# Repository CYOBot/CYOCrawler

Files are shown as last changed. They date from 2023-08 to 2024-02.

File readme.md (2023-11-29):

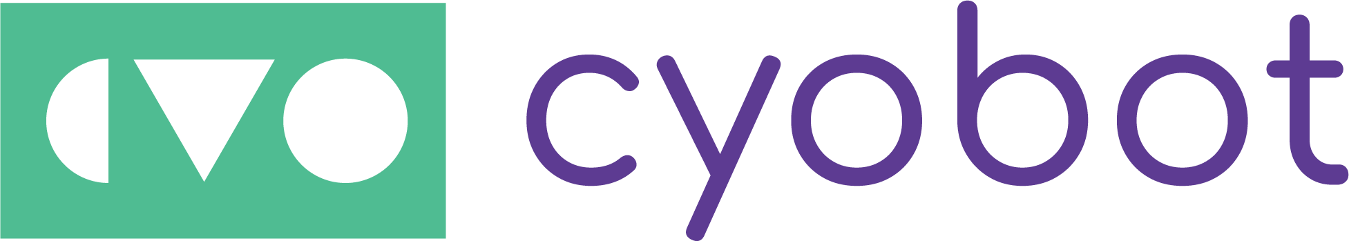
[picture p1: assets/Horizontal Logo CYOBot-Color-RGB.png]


# Introduction
This is the official repository of CYOBOT LLC **CYOCrawler, an open-source quadrupedal robotic platform**. 

CYOCrawler is the ultimate toolkit for beginner to advanced robotic adventures. The robot comes equipped with enough peripherals for most robotic applications, and extension block to connect further devices if needed. CYOCrawler comes with its own coding interface embedded, allowing seamless onboarding process for beginner, with more than enough project activities to learn and play. It is also open-source, welcoming advanced players to creatively level it up.

CYOCrawler is equipped with a wide range of capabilities to accompany you on your robotic journey:
- ESP32 Wi-Fi & Bluetooth MCU
- PCA9685 providing 12-channel servo controller
- LSM6D IMU
- Onboard speaker with MAX98357
- Onboard microphone with MAX9814
- 33-NeoPixel-LED matrix and 12-NeoPixel-LED ring
- Micro SD card reader
- USC C battery charger and smart charging/discharging system
- Extension block with power, I2C, SPI, UART, GPIO

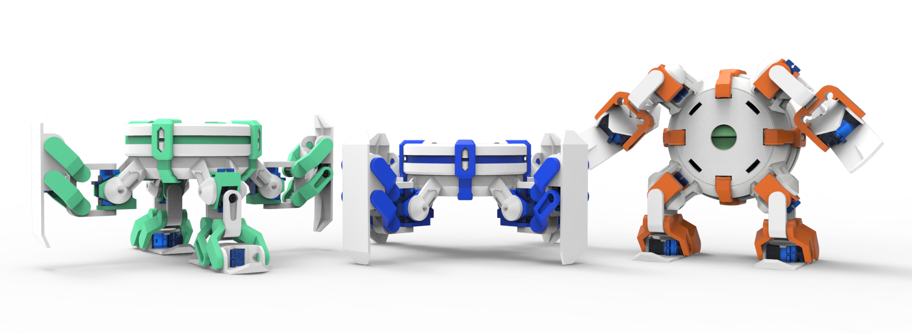
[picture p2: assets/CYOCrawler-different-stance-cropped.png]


<!-- More examples, tutorials and projects using CYOCrawler/CYOBrain can be found through [CYOBot's project library](https://cyobot.projectcocoon.org/) -->

More examples, tutorials and projects using CYOCrawler/CYOBrain can be found through [CYOBot's project library](https://cyobot.notion.site/a845040ff7484627a544b4d025d32f9d?v=201e9cd408014c6cad27ed2f8226b786&pvs=4)

Every week we publish a new challenge to our community at [r/CYOBot](https://www.reddit.com/r/CYOBot/). Join our Reddit community to participate in challenges and earn yourself a contribution on this repo. Refer to [Challenge](/challenges/readme.md) for more information.

# Technical Specification
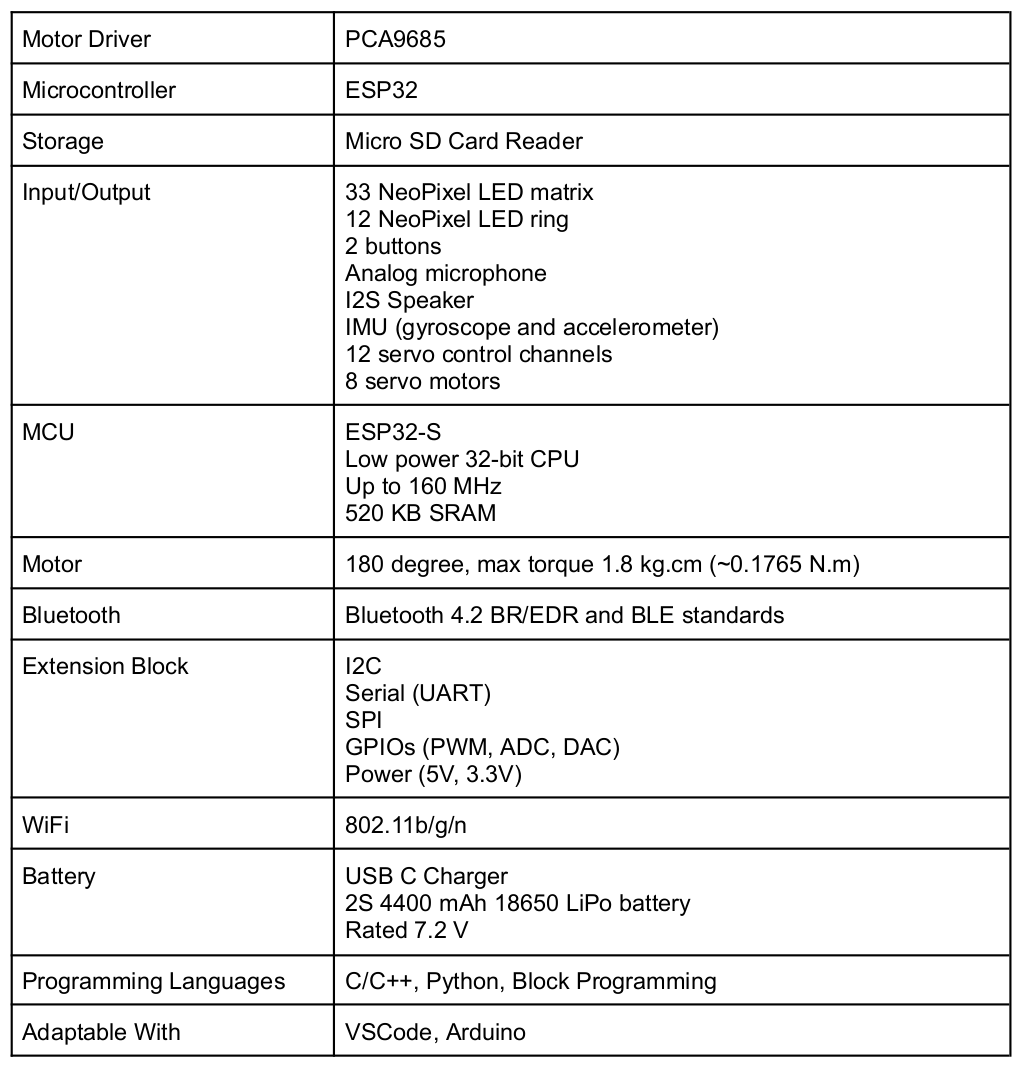
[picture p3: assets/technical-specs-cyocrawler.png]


# License
This product is open-source certified by OSHWA ([US002433](https://certification.oshwa.org/us002433.html)).

 

# Community
Follow us on social media and join the community!

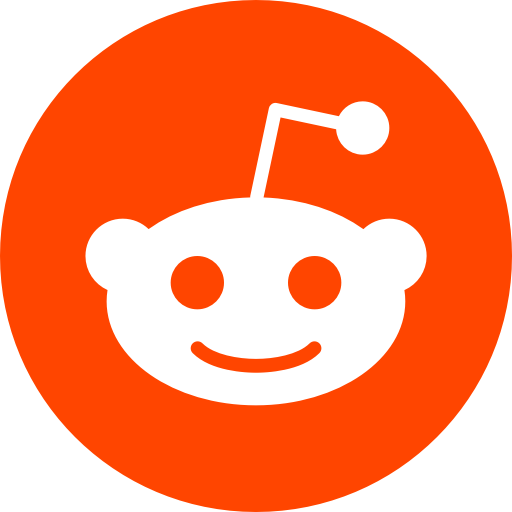
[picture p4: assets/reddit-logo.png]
[](https://www.reddit.com/r/CYOBot/)&nbsp;&nbsp;
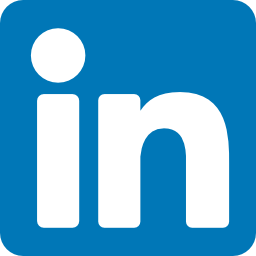
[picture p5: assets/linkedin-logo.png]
[](https://www.linkedin.com/company/cyobot)&nbsp;&nbsp;
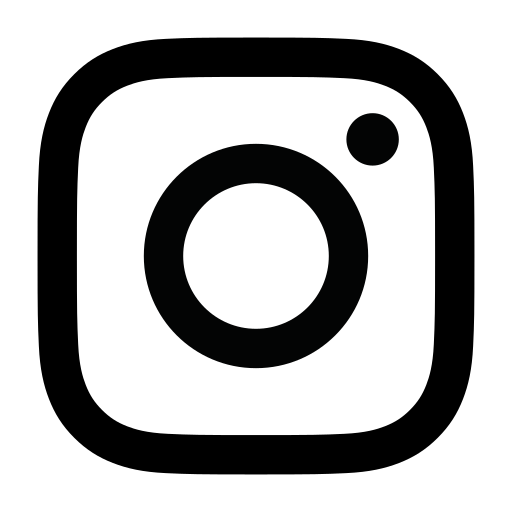
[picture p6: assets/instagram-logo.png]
[](https://www.instagram.com/cyo.bot/)&nbsp;&nbsp;

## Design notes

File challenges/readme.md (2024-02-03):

# Weekly challenge
## Introduction
The official repository and directory for all weekly challenge of CYOBot using CYOCrawler. Challenges will be posted weekly on our official [Reddit](https://www.reddit.com/r/CYOBot/), best solutions will be chosen to be announced and pull request of respective solutions will be accepted.

To get started, fork the repo, write your solution in the respective challenge solution folder, submit your video/gif of working solution on Reddit together with your Github solution link.

List of all weekly challenges as of today:
1. [Flappy Bird](flappy-bird/flappy-bird.md) (**in progress**)
2. [Dice rolling](dice-rolling/dice-rolling.md) (**in progress**)
3. [Pomodoro timer](pomodoro/pomodoro.md) (**in progress**)
4. [LED chasing game](led-chasing/led-chasing.md) (**in progress**)
5. [Simple ultrasonic radar](simple-ultrasonic-radar/simple-ultrasonic-radar.md) (**in progress**)
6. [IMU counter](imu-counter/imu-counter.md) (**in progress**)
7. [Humanoid walking](humanoid-walking/humanoid-walking.md) (**in progress**)
8. [Simple car chasing game](car-chasing-simple/car-chasing-simple.md) (**in progress**)
9. [Hybrid walking](hybrid-walking/hybrid-walking.md) (**in progress**)
10. [Simple IMU gimbal](simple-imu-gimbal/simple-imu-gimbal.md) (**in progress**)

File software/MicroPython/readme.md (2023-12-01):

# Introdution
This is the official release of CYOBot OS for CYOCrawler v2.0
The repo includes source code for onboard peripherals, including:
* Source code for robot kinematics (walking, rotating, PCA9685 control)
* Source code for NeoPixel LED Ring and LED matrix: individual LED control, text scrolling, bitmap display, etc
* Source code for micro SD card mounting
* Network management system, including AP mode and STA mode, DNS
* * Portal for coding interface and WiFi setup

# Installation
## Windows
For Windows, **esptool** and **rshell** work on top of a Conda environment. An `install.ps1` file is included to help with the process.

## Ubuntu
The `cyobot-os.bin` is the MicroPython release that works with CYOBrain v2.0

To burn the CYOBrain, install `esptool.py` to your computer, and run the following commands:

```bash
esptool.py --port <PORT> erase_flash
```
Then
```bash
esptool.py --chip esp32 --port <PORT> --baud 460800 write_flash -z 0x1000 cyobot-os.bin
```
Example if you are running this on Ubuntu

```bash
esptool.py --port /dev/ttyUSB0 erase_flash
esptool.py --chip esp32 --port /dev/ttyUSB0 --baud 460800 write_flash -z 0x1000 cyobot-os.bin
```

Then, copy content in the folder `/sd` to the micro SD card to be plugged into CYOBrain.

Next, copy all the source code from `/pyboard` folder to root directory of CYOBrain by install [rshell](https://github.com/dhylands/rshell), connect to the board running MicroPython, and call the following command:

```bash
# go to pyboard directory in this folder (not to confuse this with the root directory, /pyboard)
cd pyboard

# copy everything from the pyboard folder to the root directory of CYOBrain
rsync . /pyboard
```

Connecting to board and copying all files to board can be shorten to a single command:
```bash
rshell -p <PORT> -b 115200 rsync . /pyboard/
```

Finally, hard reset your CYOBrain by either pressing the reset button at the top of the CYOBrain, or disconnect power source (unplug USB cable/switch off the board) and reconnect. If you see the LED matrix scrolling text "AP MODE", the board is now running OS with everything else setup. Connect your computer to the board via WiFi (find the access point name `CYOCrawler`), open browser and either type in `portal.cyobot.com` or `192.168.4.1` to load the portal and start coding.

# Troubleshoot
## WebREPL is not on
The file `webrepl_cfg.py` with password information of WebREPL, and the following code in `boot.py` should be sufficient to turn on and configure WebREPL at startup:
```python
import webrepl
webrepl.start()
```

However, if WebREPL is not turned on, go through the following steps to turn on `webrepl` to be loaded on startup. Open `REPL` by typing into a terminal running `rshell` connected to CYOBrain
```bash
repl
```
Then turn on `webrepl` with:
```python
import webrepl_setup
```
Press `E` to enable webrepl on startup, and set `cyobot` as the password.

**Note**: The portal will attempt to connect to CYOBrain via webrepl with the password `cyobot`, so if you set the password to be anything else, the connection will not be successfully established.

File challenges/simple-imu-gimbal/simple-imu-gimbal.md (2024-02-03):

# Simple IMU gimbal to stabilize robot

**Description**: 
* **Deliverables**: Write a function
* **Visible outcome**: To balance the robot's angles on an angle-varying platform
* **Techstacks**: Using IMU sensor to read angle rate and linear acceleration to determine the offset angle and write the offset value to robot's joints
* **Constraints**: N/A

<p align="center">
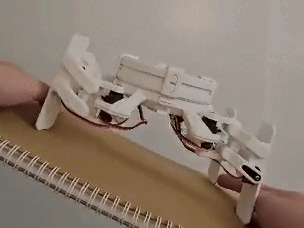
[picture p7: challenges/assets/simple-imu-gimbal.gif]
    
</p>

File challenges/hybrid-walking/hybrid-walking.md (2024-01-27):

# Make robot walk in hybrid form

**Description**: 
* **Deliverables**: Write a script or program
* **Visible outcome**: Control the robot to walk in hybrid form
* **Techstacks**: Using the provided functions of the `Crawler()` class to manipulate correct motors in correct trajectories
* **Constraints**: N/A

<p align="center">
    
</p>

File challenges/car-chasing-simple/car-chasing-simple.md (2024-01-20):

# Simple car chasing game on CYOCrawler

**Description**: 
* **Deliverables**: Write a program that runs when boot up
* **Visible outcome**: Running a simple car chasing game on CYOCrawler
* **Techstacks**: With buttons to move car left and right, LED matrix to display game and speaker to play sound when moving and when got hit by other cars.
* **Constraints**: N/A

<p align="center">
    
</p>

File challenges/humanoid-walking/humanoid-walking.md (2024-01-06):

# Make robot walk in humanoid form

**Description**: 
* **Deliverables**: Write a script or program
* **Visible outcome**: Control the robot to walk in humanoid form
* **Techstacks**: Using the provided functions of the `Crawler()` class to manipulate correct motors in correct trajectories
* **Constraints**: N/A

<p align="center">
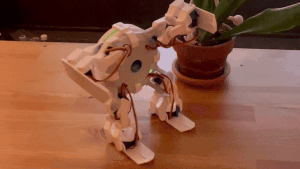
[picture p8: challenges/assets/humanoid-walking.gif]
    
</p>

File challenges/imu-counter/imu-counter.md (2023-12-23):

# IMU counter for CYOCrawler

**Description**: 
* **Deliverables**: Write a function
* **Visible outcome**: Display a number that counts how many times the robot is shaken left or right
* **Techstacks**: Using IMU sensor to detect shakes, LED matrix to display number
* **Constraints**: N/A

<p align="center">
    
</p>

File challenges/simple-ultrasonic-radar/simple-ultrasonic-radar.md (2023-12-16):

# Turn CYOCrawler into a simple ultrasonic radar

**Description**
* **Deliverables**: Write a program that runs when boot up
* **Visible outcome**: Turn CYOCrawler into a simple ultrasonic radar
* **Techstacks**: Using external ultrasonic sensor connected to robot via extension block to detect distance to obstacles/objects, LED ring to display distance to contact: red for close, green for far.
* **Constraints**: N/A

<p align="center">
    
</p>

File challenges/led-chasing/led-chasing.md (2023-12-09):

# LED chasing game on CYOCrawler

**Description**: 
* **Deliverables**: Write a program that runs when boot up
* **Visible outcome**: Running a simple LED chasing game on CYOCrawler
* **Techstacks**: With button to stop the running LED, LED matrix to show game result, and LED ring to display the running LED and the goal position.
* **Constraints**: N/A

<p align="center">
    
</p>

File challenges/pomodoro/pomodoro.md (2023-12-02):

# Turn CYOCrawler into a Pomodoro timer

**Description**
* **Deliverables**: Write a program that runs when boot up
* **Visible outcome**: Turn CYOCrawler into a Pomodoro timer
* **Techstacks**: Using buttons to set the time (utilizing different modes of a button: press, press and hold, double-press, etc), LED screen to show the minutes left, LED ring to show the seconds count down of the current minute, LED screen, speaker and movements of robot to notify when time is up.
* **Constraints**: N/A

<p align="center">
    
</p>

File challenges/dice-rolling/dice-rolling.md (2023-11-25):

# Dice rolling effect on CYOCrawler

**Description**: 
* **Deliverables**: Write a program that runs when boot up
* **Visible outcome**: An electric dice with 6 faces that you can shake to change
* **Techstacks**: With IMU sensor reading to roll the dice
* **Constraints**: N/A

<p align="center">
    
</p>

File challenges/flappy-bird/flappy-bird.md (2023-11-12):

# Flappy Bird game on CYOCrawler

**Description**: 
* **Deliverables**: Write a program that runs when boot up
* **Visible outcome**: Running Flappy Bird-like game on CYOCrawler
* **Techstacks**: With buttons to jump, LED matrix to display game and speaker to play sound when jump
* **Constraints**: N/A

<p align="center">
    
</p>

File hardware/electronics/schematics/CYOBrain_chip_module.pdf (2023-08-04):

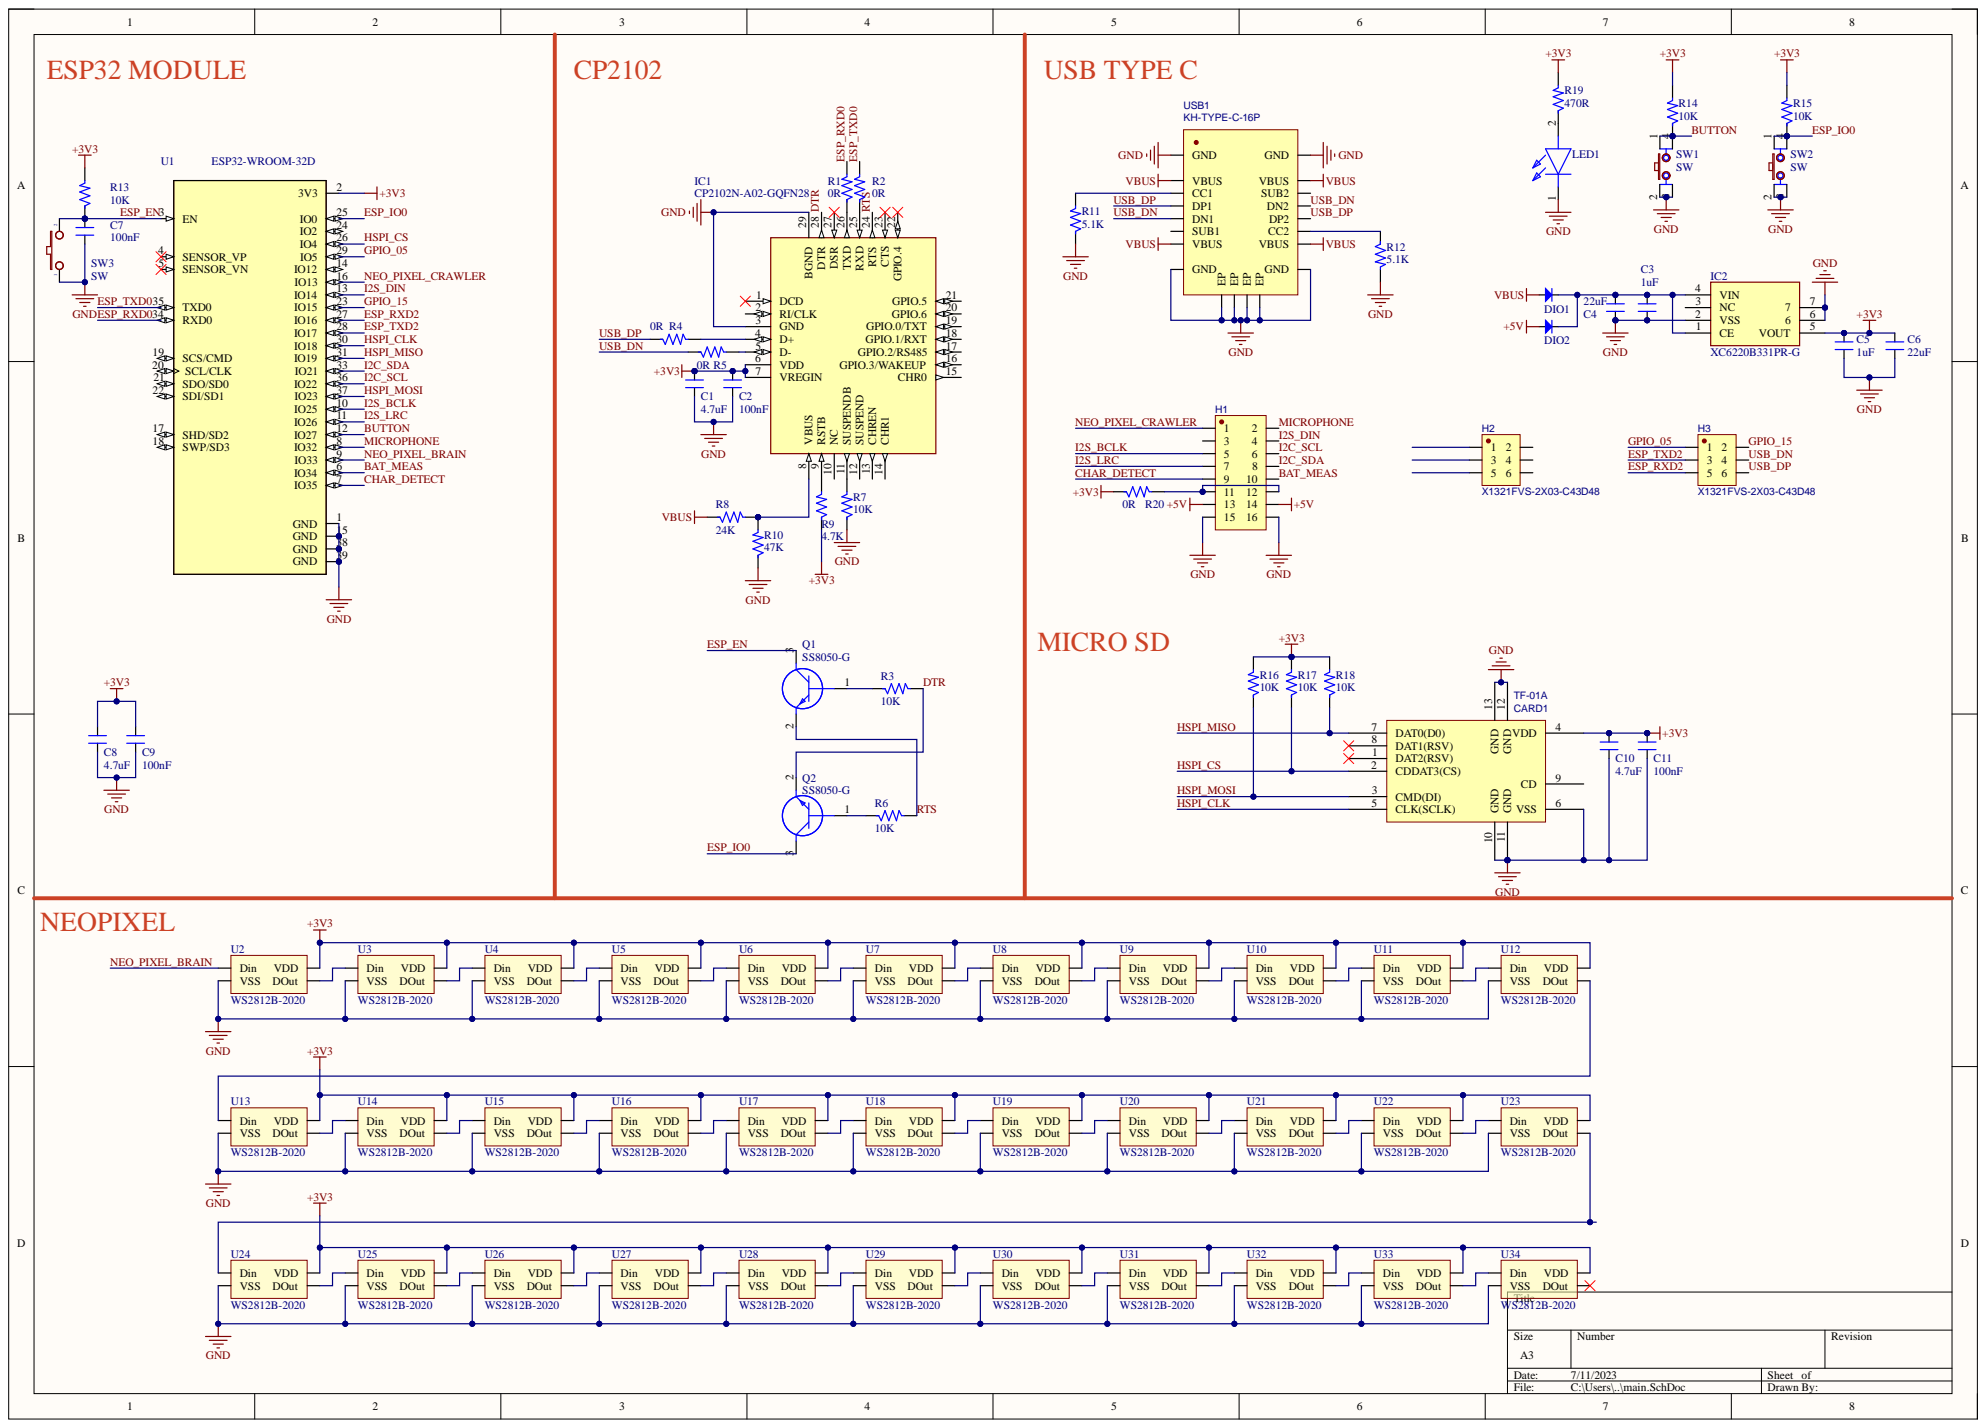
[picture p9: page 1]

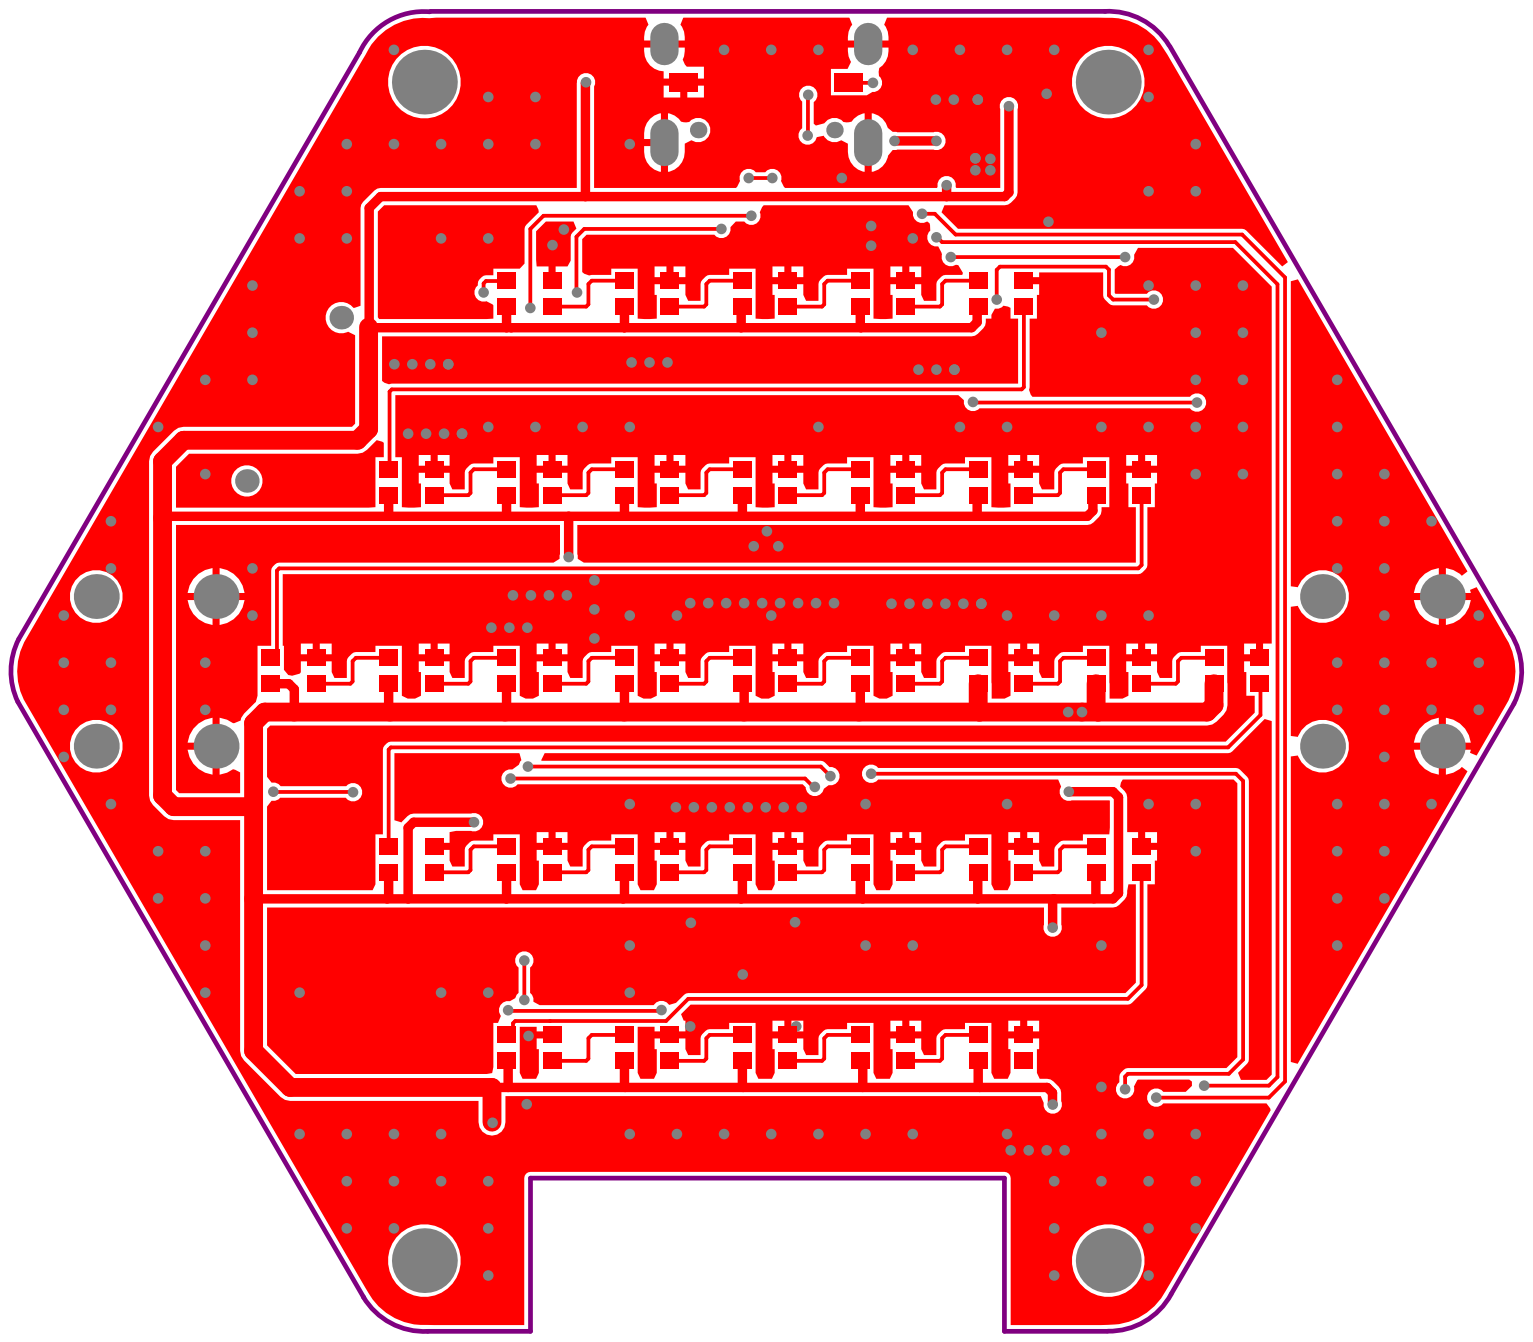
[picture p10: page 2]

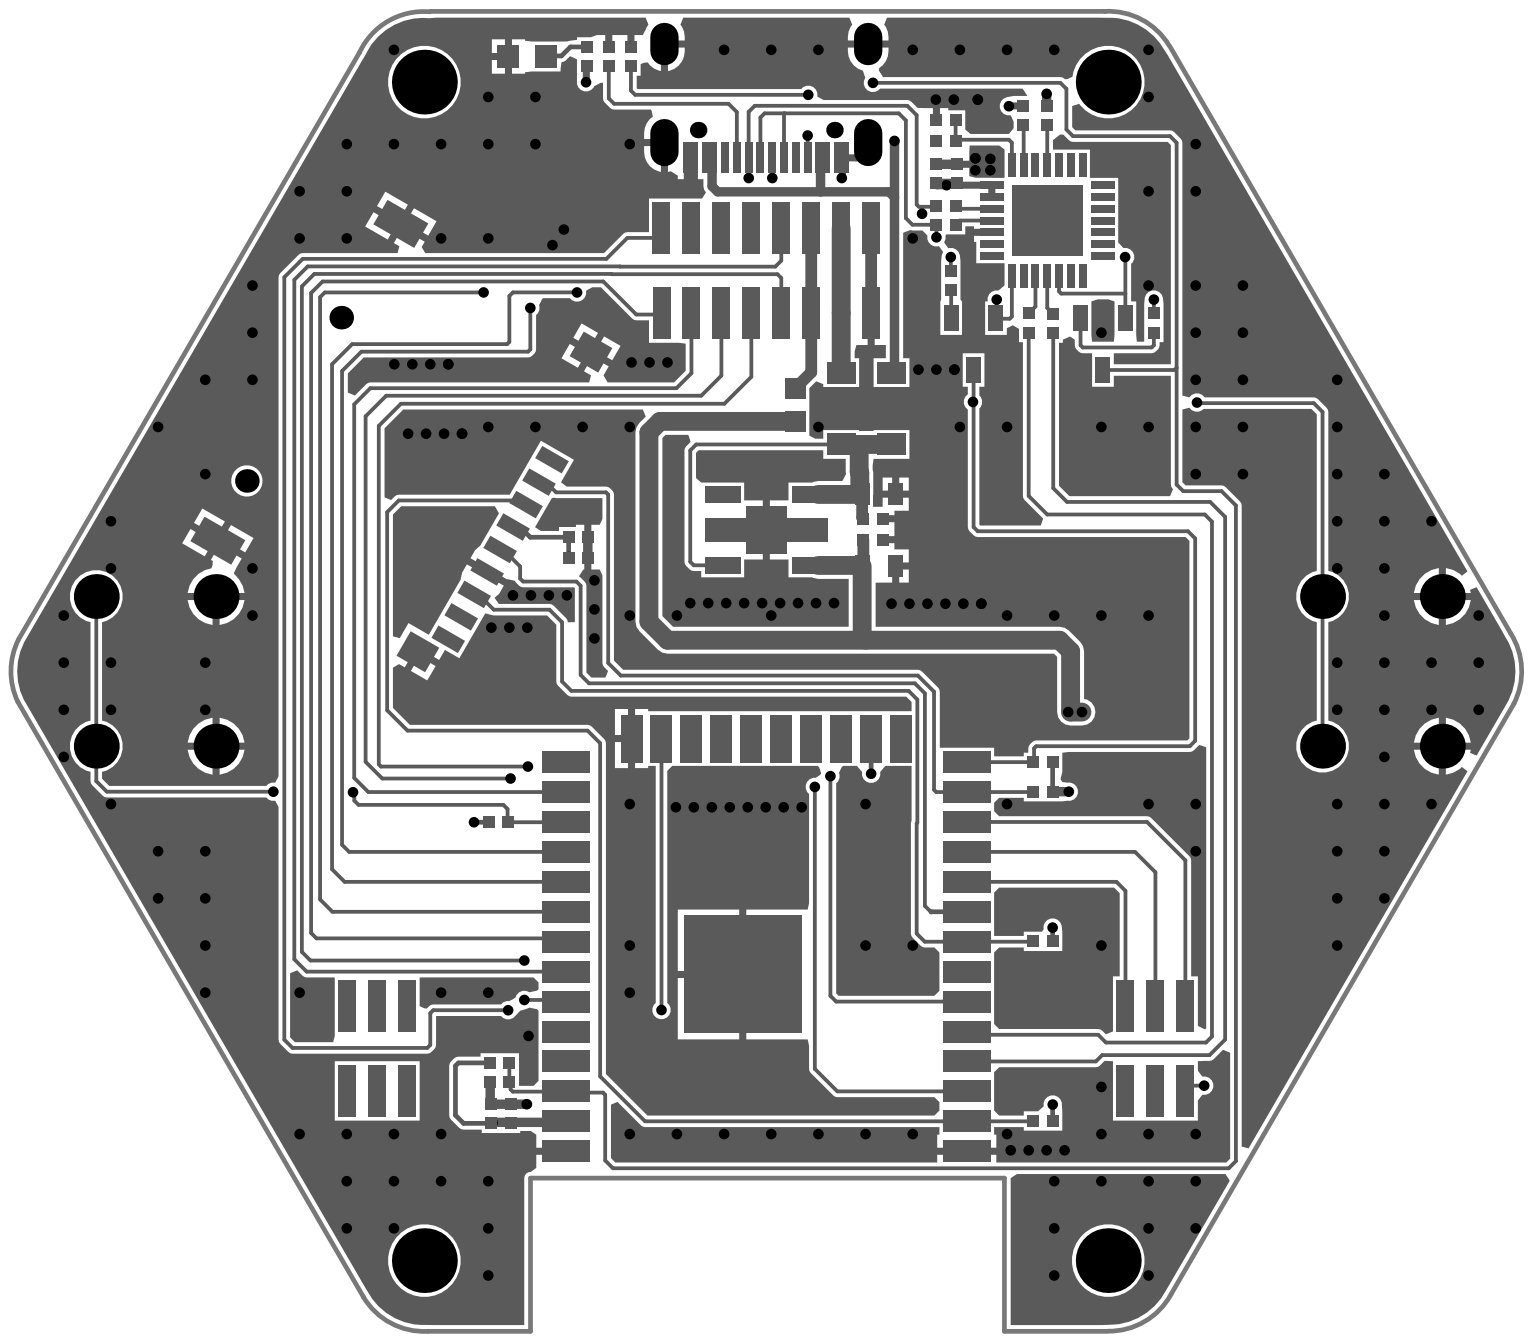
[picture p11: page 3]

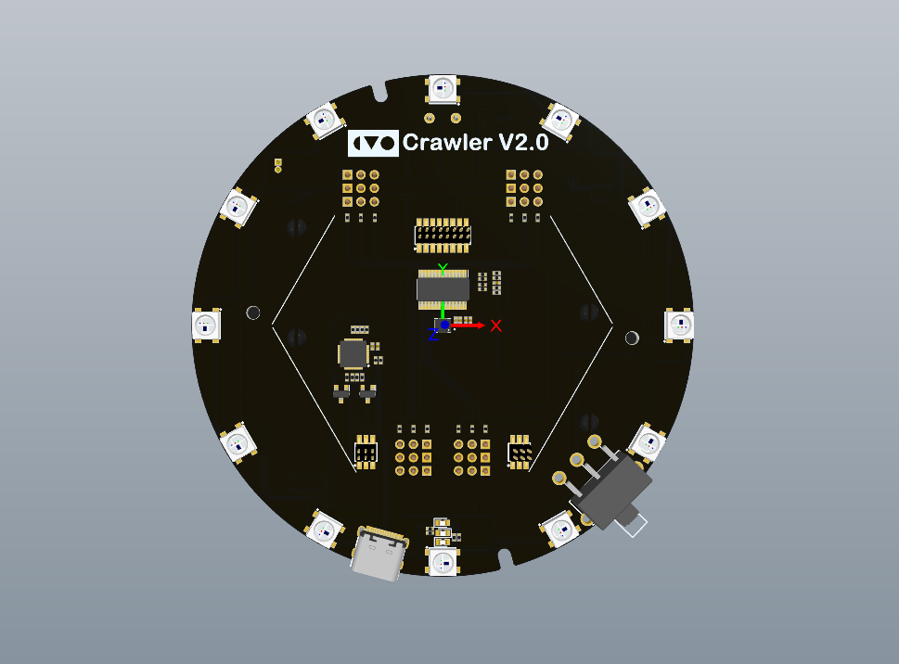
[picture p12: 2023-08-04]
hardware/electronics/assets/Crawler_V2.0_Top.png

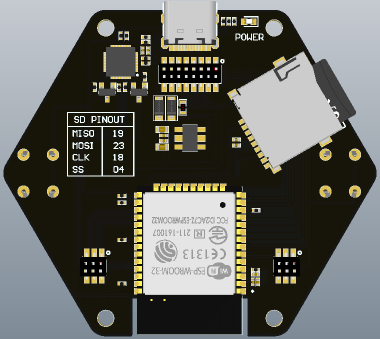
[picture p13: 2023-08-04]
hardware/electronics/assets/Crawler_Brain_Bot.png

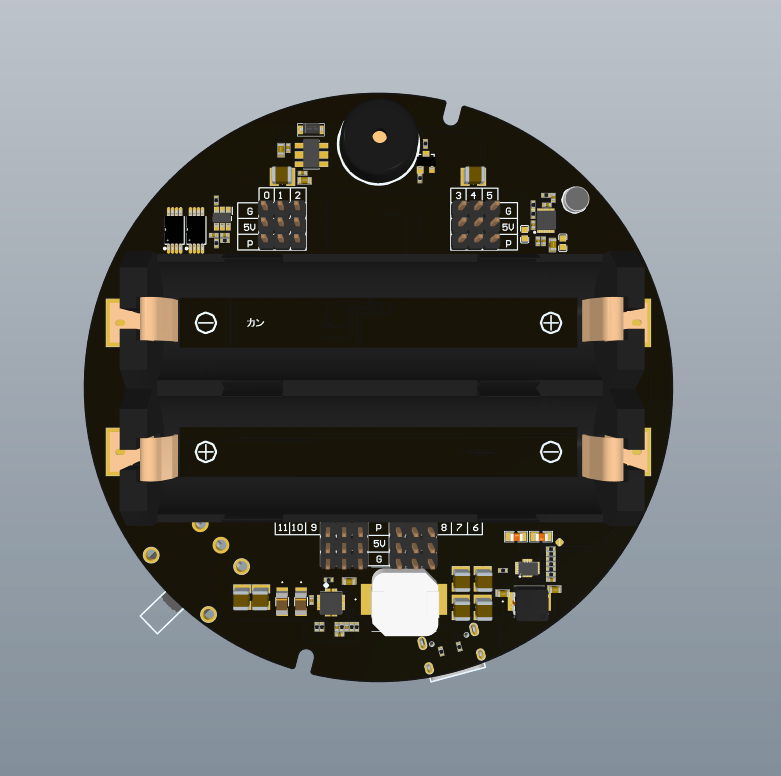
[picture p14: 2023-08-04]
hardware/electronics/assets/Crawler_V2.0_Bot.png

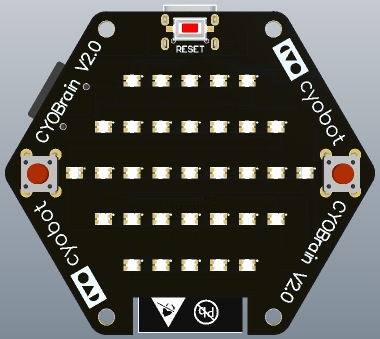
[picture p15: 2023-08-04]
hardware/electronics/assets/Crawler_Brain_Top.png

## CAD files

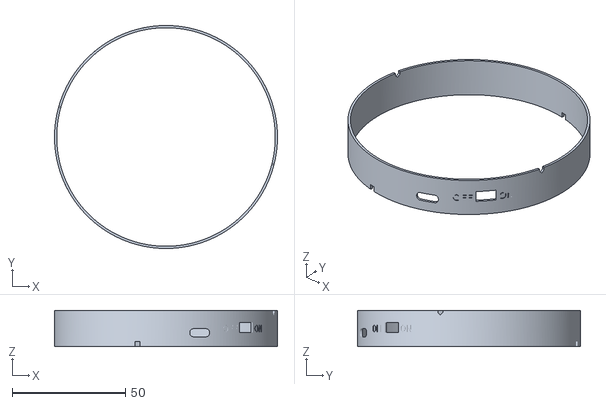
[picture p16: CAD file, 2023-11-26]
hardware/mechanical/STLs/CYOCRAWLER HEAD LIGHT DIFFUSER v2 X1.stl
98.5 x 98.5 x 16.0

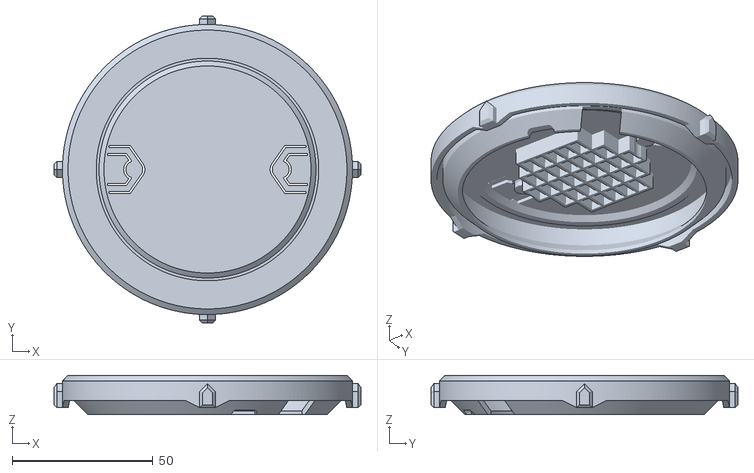
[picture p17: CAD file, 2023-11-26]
hardware/mechanical/STLs/CYOCRAWLER HEAD TOP CAP v3 X1.stl
109.0 x 109.0 x 14.0

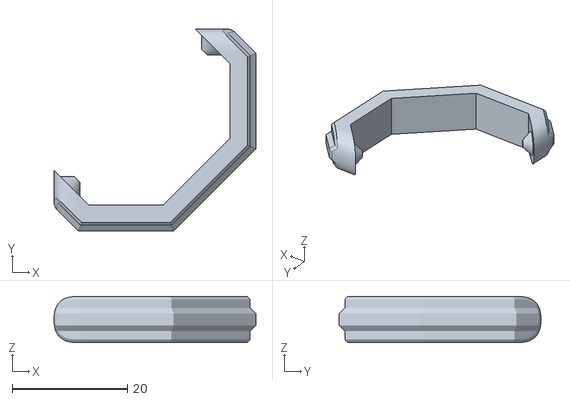
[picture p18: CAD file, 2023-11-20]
hardware/mechanical/STLs/CYOCRAWLER HIP SERVO CLAMP v2 X4.stl
35.1 x 35.1 x 8.00

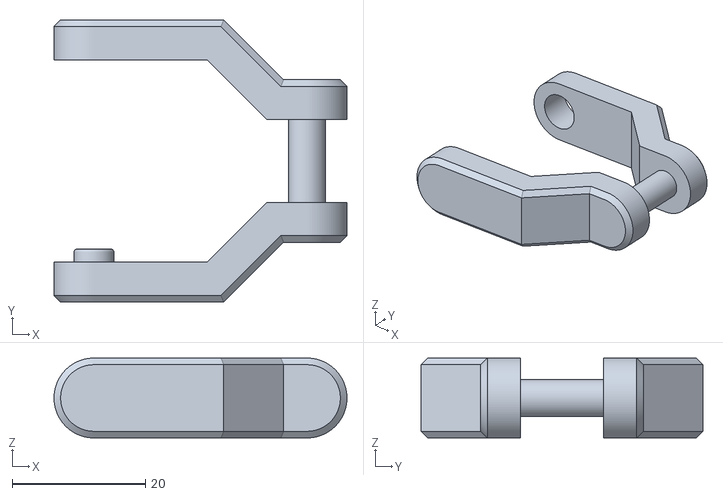
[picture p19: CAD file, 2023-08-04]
hardware/mechanical/STLs/CYOCRAWLER FEET CONNECTOR SERVO X4.stl
44.0 x 42.4 x 12.0

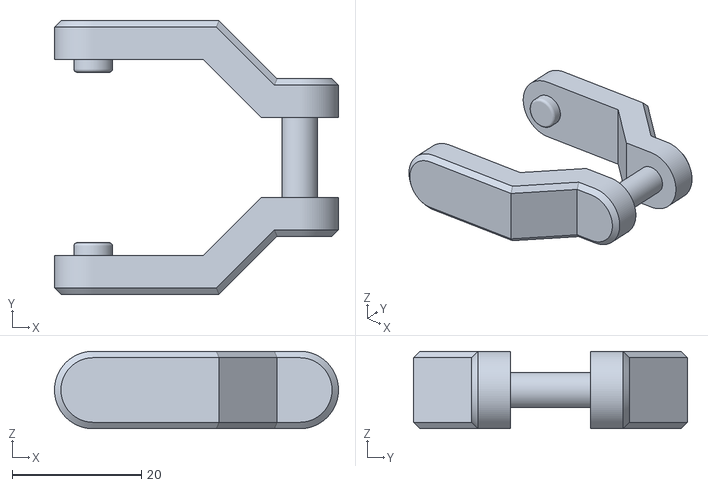
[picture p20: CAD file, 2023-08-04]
hardware/mechanical/STLs/CYOCRAWLER FEET CONNECTOR X4.stl
44.0 x 42.4 x 12.0

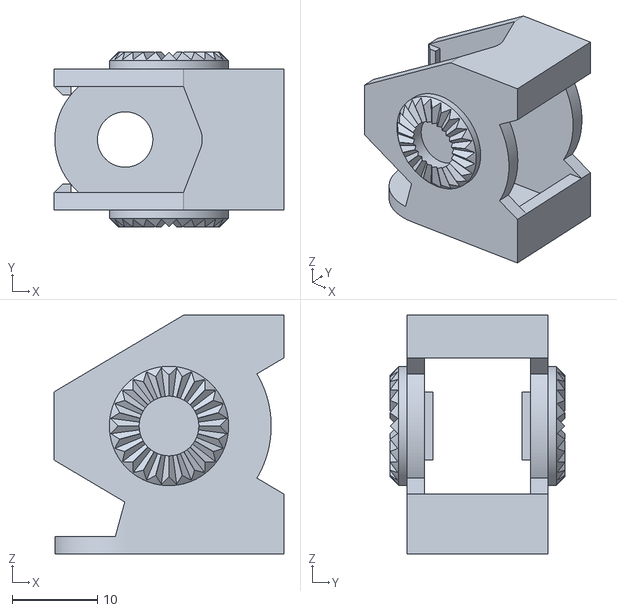
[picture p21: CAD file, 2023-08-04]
hardware/mechanical/STLs/CYOCRAWLER HIP SERVO HOLDER X4.stl
27.0 x 20.5 x 28.0

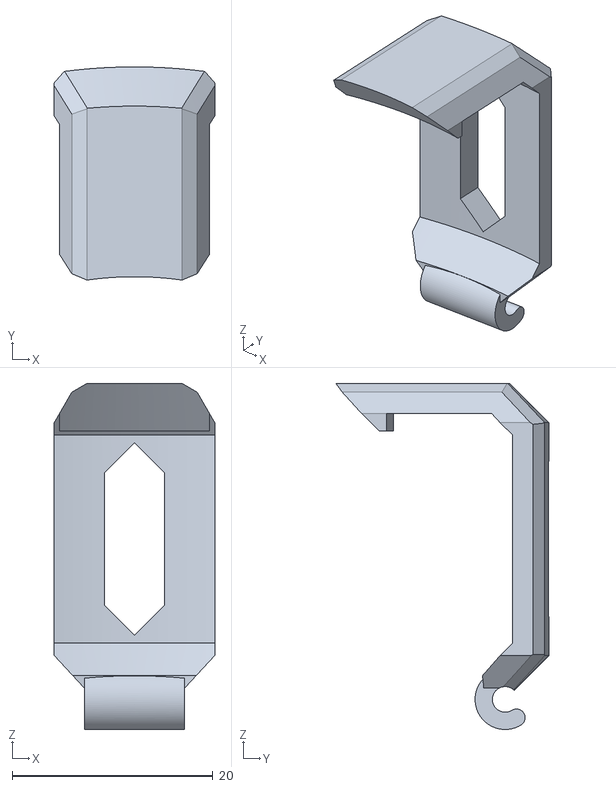
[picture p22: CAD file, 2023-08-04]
hardware/mechanical/STLs/CYOCRAWLER HEAD CLAMP X4.stl
16.0 x 21.2 x 34.5

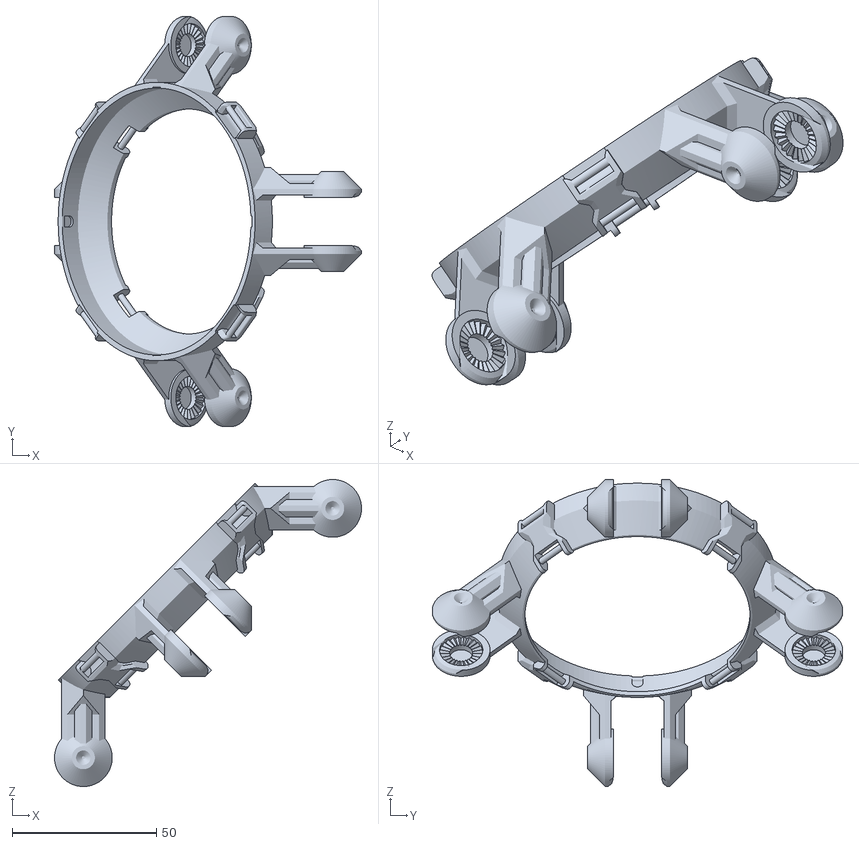
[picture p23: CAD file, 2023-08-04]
hardware/mechanical/STLs/CYOCRAWLER HIP X1.stl
106.4 x 142.2 x 106.4

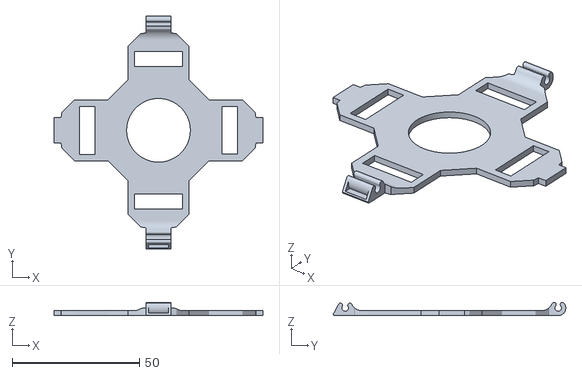
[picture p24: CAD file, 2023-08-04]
hardware/mechanical/STLs/CYOCRAWLER HIP BATTERY COVER X1.stl
82.1 x 91.4 x 5.24

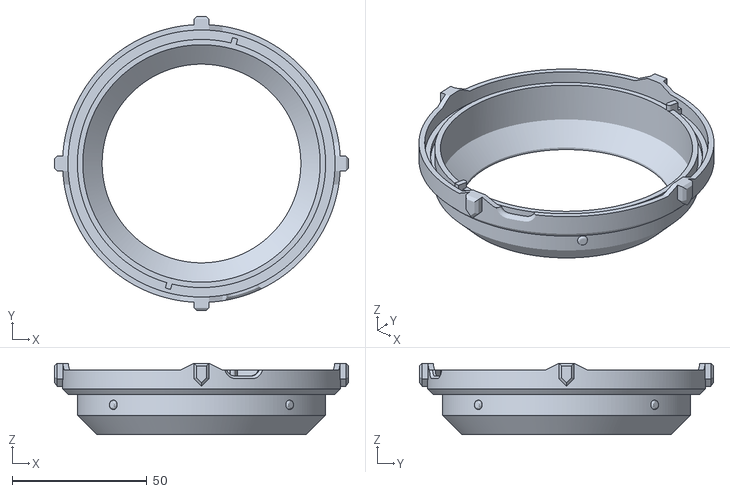
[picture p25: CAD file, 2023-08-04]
hardware/mechanical/STLs/CYOCRAWLER HEAD BOTTOM CAP X1.stl
109.0 x 109.0 x 26.5

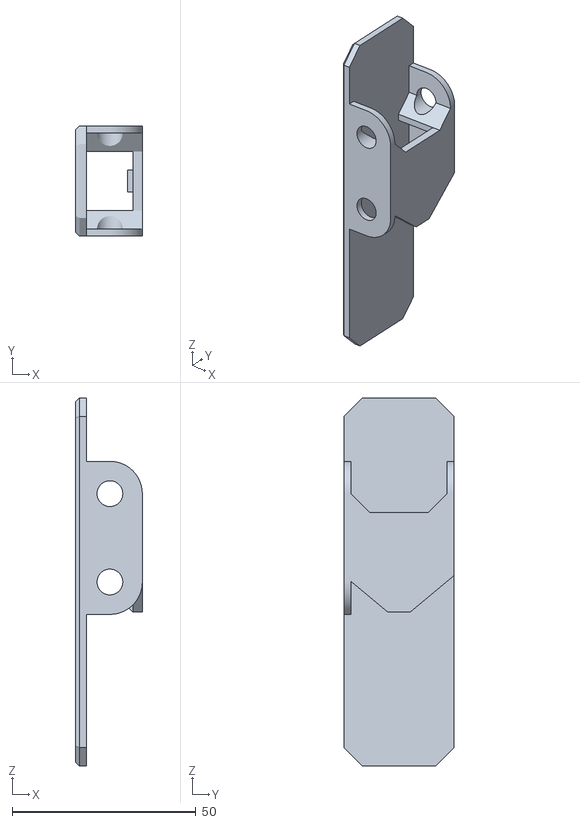
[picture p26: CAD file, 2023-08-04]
hardware/mechanical/STLs/CYOCRAWLER FEET X4.stl
18.1 x 30.0 x 100.0

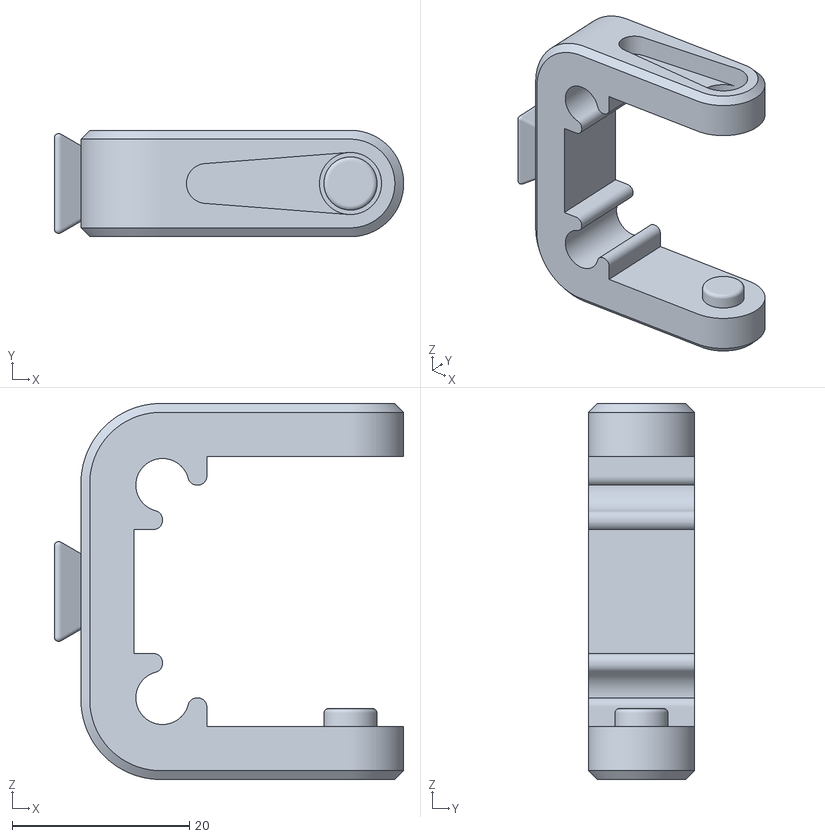
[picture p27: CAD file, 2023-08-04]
hardware/mechanical/STLs/CYOCRAWLER HIP CONNECTOR SERVO X4.stl
39.4 x 12.0 x 42.4

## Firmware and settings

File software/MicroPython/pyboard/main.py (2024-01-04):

from lib.crawler.display import *
from lib.brain.display import *
import time

# check to see if button is pressed down
left = machine.Pin(27, machine.Pin.IN)
right = machine.Pin(0, machine.Pin.IN)

ring = LEDRing()
matrix = Matrix()
ring.reset()
matrix.reset()

if left.value() == 0:
    for i in range(12):
        ring.set_manual(i, (100, 0, 0))
        time.sleep(0.05)
    
    # enter factory reset mode
    cur_time = time.time()

    from lib.brain.display import *
    matrix.reset()
    while time.time() - cur_time < 3:
        if left.value() != 0:
            machine.reset()
    
    matrix.scroll("RESET", blue=100, speed=0.05)
    # run factory reset
    import json
    ## fix portal config file
    file = open("/sd/portal/config.json").read()
    content = json.loads(file)
    content["pythonWebREPL"]["endpoint"] = "ws://192.168.4.1:8266"
    content["onboarding"]["hasProvidedWifiCredentials"] = False
    
    with open("/sd/portal/config.json", "w") as outfile:
        outfile.write(json.dumps(content))
    
    ## fix brain config file
    with open("/sd/lib/brain/config.json", "w") as outfile:
        outfile.write(json.dumps({}))

for i in range(12):
    ring.set_manual(i, (0, 100, 0))
    time.sleep(0.05)
ring.reset()

try:
    del file
    del outfile
except:
    pass

import network
from lib.network.microWebSrv import MicroWebSrv
from lib.brain.wireless import *
import json
import webrepl

wifi = WiFi()

try:
    file = open("/sd/lib/brain/config.json").read()
    content = json.loads(file)
    wifi.connect(content["ssid"], content["password"], verbose=True)
    del file
except:
    pass

def getWiFiAPList():
    def signal_strength(x):
        if x < -80:
            return 0
        elif x < -60:
            return 1
        elif x < -40:
            return 2
        else:
            return 3
    
    try:
        ap_list = wifi.wlan.scan()
    except:
        try:
            ap_list = ap.scan()
        except:
            pass
    content = [{"ssid": x[0].decode('ascii'), "strength": signal_strength(x[3])} for x in ap_list]
    return content

last_wifi_ap_list = getWiFiAPList()
last_wifi_ap_scan_time = time.time()

"""
for i in range(12):
    self.np[i] = (red, green, blue)
    self.np.write()
    time.sleep(speed)
for i in range(12):
    self.np[i] = (0, 0, 0)
    self.np.write()
    time.sleep(speed)
"""

if wifi.wlan.isconnected():
    from lib.crawler.sound import Speaker
    speaker = Speaker()
    ring.np[0] = (0, 100, 0)
    ring.np.write()
    ring.np[1] = (0, 100, 0)
    ring.np.write()
    speaker.play_tone(frequency=261, duration=0.2, volume=2)
    time.sleep(0.01)
    ring.np[2] = (0, 100, 0)
    ring.np.write()
    ring.np[3] = (0, 100, 0)
    ring.np.write()
    speaker.play_tone(frequency=392, duration=0.2, volume=2)
    time.sleep(0.01)
    ring.np[4] = (0, 100, 0)
    ring.np.write()
    ring.np[5] = (0, 100, 0)
    ring.np.write()
    speaker.play_tone(frequency=659, duration=0.2, volume=2)
    time.sleep(0.01)
    ring.np[6] = (0, 100, 0)
    ring.np.write()
    ring.np[7] = (0, 100, 0)
    ring.np.write()
    speaker.play_tone(frequency=1047, duration=0.2, volume=2)
    time.sleep(0.01)
    for i in range(8, 12):
        ring.np[i] = (0, 100, 0)
        ring.np.write()
        time.sleep(0.1)
    for i in range(12):
        ring.np[i] = (0, 0, 0)
        ring.np.write()
        time.sleep(0.1)

    file = open("/sd/portal/config.json").read()
    content = json.loads(file)
    content["pythonWebREPL"]["endpoint"] = "ws://{}:8266".format(wifi.wlan.ifconfig()[0])
    content["onboarding"]["hasProvidedWifiCredentials"] = True
    del file
    
    with open("/sd/portal/config.json", "w") as outfile:
        outfile.write(json.dumps(content))
    del outfile
else:
    file = open("/sd/portal/config.json").read()
    content = json.loads(file)
    content["pythonWebREPL"]["endpoint"] = "ws://192.168.4.1:8266"
    content["onboarding"]["hasProvidedWifiCredentials"] = False
    del file
    
    with open("/sd/portal/config.json", "w") as outfile:
        outfile.write(json.dumps(content))
    del outfile

ssid = 'CYOBot'

ap = network.WLAN(network.AP_IF)
ap.active(True)
ap.config(essid=ssid, pm=network.WLAN.PM_PERFORMANCE, txpower=20, channel=6)

while ap.active() == False:
    pass

print('Connection successful')
print(ap.config('essid'), ap.ifconfig())

if not wifi.wlan.isconnected():
    from lib.network.microDNSSrv import MicroDNSSrv
    if MicroDNSSrv.Create({"portal.cyobot.com": "192.168.4.1"}):
        print("MicroDNSSrv started.")
    else :
        print("Error to starts MicroDNSSrv...")

# handle request from portal
@MicroWebSrv.route('/api/config')
def _httpHandlerGetConfig(httpClient, httpResponse):
    httpResponse.WriteResponseFile("/sd/portal/config.json", contentType="application/json", headers={
        'Access-Control-Allow-Origin': '*',
        'Access-Control-Allow-Methods': '*',
        'Access-Control-Allow-Headers': '*'
    })

@MicroWebSrv.route('/api/internet')
def _httpHandlerGetWiFiConnectivity(httpClient, httpResponse):
    if wifi.wlan.isconnected():
        httpResponse.WriteResponseJSONOk(obj=json.loads('{"status": "connected"}'), headers={
            'Access-Control-Allow-Origin': '*',
            'Access-Control-Allow-Methods': '*',
            'Access-Control-Allow-Headers': '*'
        })
    else:
        httpResponse.WriteResponseJSONOk(obj=json.loads('{"status": "disconnected"}'), headers={
            'Access-Control-Allow-Origin': '*',
            'Access-Control-Allow-Methods': '*',
            'Access-Control-Allow-Headers': '*'
        })

@MicroWebSrv.route('/api/wifi')
def _httpHandlerGetWiFi(httpClient, httpResponse):
    global last_wifi_ap_list
    global last_wifi_ap_scan_time
    if time.time() - last_wifi_ap_scan_time > 10:
        last_wifi_ap_list = getWiFiAPList()
        last_wifi_ap_scan_time = time.time()
    httpResponse.WriteResponseJSONOk(obj=last_wifi_ap_list, headers={
        'Access-Control-Allow-Origin': '*',
        'Access-Control-Allow-Methods': '*',
        'Access-Control-Allow-Headers': '*'
    })

@MicroWebSrv.route('/api/wifi', method='OPTIONS')
def _httpHandlerOptionWiFiCredential(httpClient, httpResponse):
    httpResponse.WriteResponseOk(headers={
        'Access-Control-Allow-Origin': '*',
        'Access-Control-Allow-Methods': '*',
        'Access-Control-Allow-Headers': '*'
    })

@MicroWebSrv.route('/api/wifi', 'POST')
def _httpHandlerPostWiFiCredential(httpClient, httpResponse):
    # receive credentials from portal
    # attempt to connect
    # if successful, update config.json (pythonwebrepl --> ws://<NEW IP>:8266) AND onboarding.hasProvidedWifiCredentials --> True
    # if not, do not need to update
    # return "success" or "fail" to client
    data = httpClient.ReadRequestContentAsJSON()

    # try 4 times (5 seconds/time)
    for i in range(4):
        wifi.connect(data["ssid"], data["password"], verbose=True)
        if wifi.wlan.isconnected():
            break

    #! TODO: also store this credential in INTERNAL config so that we can connect in the future auto
    if wifi.wlan.isconnected():
        file = open("/sd/portal/config.json").read()
        content = json.loads(file)
        content["pythonWebREPL"]["endpoint"] = "ws://{}:8266".format(wifi.wlan.ifconfig()[0])
        content["onboarding"]["hasProvidedWifiCredentials"] = True
        del file
        
        with open("/sd/portal/config.json", "w") as outfile:
            outfile.write(json.dumps(content))
        del outfile

        file = open("/sd/lib/brain/config.json").read()
        content = json.loads(file)
        content["ssid"] = data["ssid"]
        content["password"] = data["password"]
        del file

        with open("/sd/lib/brain/config.json", "w") as outfile:
            outfile.write(json.dumps(content))
        del outfile

        httpResponse.WriteResponseJSONOk(obj=json.dumps("success"), headers={
            'Access-Control-Allow-Origin': '*',
            'Access-Control-Allow-Methods': '*',
            'Access-Control-Allow-Headers': '*'
        })
        
        time.sleep(2)
        import machine
        machine.reset()

    else:
        httpResponse.WriteResponseJSONOk(obj=json.dumps("fail"), headers={
            'Access-Control-Allow-Origin': '*',
            'Access-Control-Allow-Methods': '*',
            'Access-Control-Allow-Headers': '*'
        })

# @MicroWebSrv.route('/api/config', method='OPTIONS')
# def _httpHandlerOptionConfig(httpClient, httpResponse):
#     httpResponse.WriteResponseOk(headers={
#         'Access-Control-Allow-Origin': '*',
#         'Access-Control-Allow-Methods': '*',
#         'Access-Control-Allow-Headers': '*'
#     })

@MicroWebSrv.route('/api/config', 'POST')
def _httpHandlerPostConfig(httpClient, httpResponse):
    data = httpClient.ReadRequestContentAsJSON()
    print(data)
    
    try:
        file = open("/sd/portal/config.json").read()
        content = json.loads(file)
        content["pythonWebREPL"]["endpoint"] = data["wsEndpoint"]
        del file
        
        with open("/sd/portal/config.json", "w") as outfile:
            outfile.write(json.dumps(content))
        del outfile
        
        httpResponse.WriteResponseOk(headers={
            'Access-Control-Allow-Origin': '*',
            'Access-Control-Allow-Methods': '*',
            'Access-Control-Allow-Headers': '*'
        })
    except Exception as e:
        print(e)
        httpResponse.WriteReponseError(500, headers={
            'Access-Control-Allow-Origin': '*',
            'Access-Control-Allow-Methods': '*',
            'Access-Control-Allow-Headers': '*'
        })

srv = MicroWebSrv(webPath='/sd/portal/')

# if not wifi.wlan.isconnected():
    # matrix.scroll("AP MODE", speed=0.05, red=0, green=0, blue=80)

srv.Start(threaded=True)

import webrepl
if wifi.wlan.isconnected():
    ip_address = wifi.wlan.ifconfig()[0]
    character_list = [char for char in ip_address]
    offset_list = [(-7*i) for i in range(len(character_list))]
    
    matrix.reset()
    for i in range(len(character_list)):
        if offset_list[i] <= 6 and offset_list[i] >=-6:
            matrix.set_character(character_list[i], offset = offset_list[i] // 1, multiplex = True, blue = 100)
    matrix.np.write()
    
    redraw = False
    
    while webrepl.client_s is None:
        redraw = False

        if left.value() != 0 and right.value() == 0:
            for i in range(len(offset_list)):
                offset_list.append(offset_list.pop(0) + 0.1)
            redraw = True
        elif right.value() != 0 and left.value() == 0:
            for i in range(len(offset_list)):
                offset_list.append(offset_list.pop(0) - 0.1)
            redraw = True
        
        if redraw:
            matrix.reset()
            for i in range(len(character_list)):
                if offset_list[i] <= 6 and offset_list[i] >=-6:
                    matrix.set_character(character_list[i], offset = offset_list[i] // 1, multiplex = True, blue = 100)
            matrix.np.write()
        else:
            time.sleep(1.0)
else:
    on=True
    while webrepl.client_s is None:
        if on:
            matrix.reset()
            on = False
        else:
            matrix.set_manual(16, (100, 0, 100))
            on = True
        time.sleep(1.0)

matrix.reset()

globals().pop("ring", None)
globals().pop("LEDRing", None)
globals().pop("matrix", None)
globals().pop("Matrix", None)
globals().pop("speaker", None)
globals().pop("Speaker", None)
globals().pop("left", None)
globals().pop("right", None)
globals().pop("content", None)
globals().pop("webrepl", None)

import gc
gc.collect()
gc.mem_free()
gc.mem_alloc()

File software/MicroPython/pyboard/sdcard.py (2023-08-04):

"""
MicroPython driver for SD cards using SPI bus.

Requires an SPI bus and a CS pin.  Provides readblocks and writeblocks
methods so the device can be mounted as a filesystem.

Example usage on pyboard:

    import pyb, sdcard, os
    sd = sdcard.SDCard(pyb.SPI(1), pyb.Pin.board.X5)
    pyb.mount(sd, '/sd2')
    os.listdir('/')

Example usage on ESP8266:

    import machine, sdcard, os
    sd = sdcard.SDCard(machine.SPI(1), machine.Pin(15))
    os.mount(sd, '/sd')
    os.listdir('/')

"""

from micropython import const
import time


_CMD_TIMEOUT = const(100)

_R1_IDLE_STATE = const(1 << 0)
# R1_ERASE_RESET = const(1 << 1)
_R1_ILLEGAL_COMMAND = const(1 << 2)
# R1_COM_CRC_ERROR = const(1 << 3)
# R1_ERASE_SEQUENCE_ERROR = const(1 << 4)
# R1_ADDRESS_ERROR = const(1 << 5)
# R1_PARAMETER_ERROR = const(1 << 6)
_TOKEN_CMD25 = const(0xFC)
_TOKEN_STOP_TRAN = const(0xFD)
_TOKEN_DATA = const(0xFE)


class SDCard:
    def __init__(self, spi, cs, baudrate=1320000):
        self.spi = spi
        self.cs = cs

        self.cmdbuf = bytearray(6)
        self.dummybuf = bytearray(512)
        self.tokenbuf = bytearray(1)
        for i in range(512):
            self.dummybuf[i] = 0xFF
        self.dummybuf_memoryview = memoryview(self.dummybuf)

        # initialise the card
        self.init_card(baudrate)

    def init_spi(self, baudrate):
        try:
            master = self.spi.MASTER
        except AttributeError:
            # on ESP8266
            self.spi.init(baudrate=baudrate, phase=0, polarity=0)
        else:
            # on pyboard
            self.spi.init(master, baudrate=baudrate, phase=0, polarity=0)

    def init_card(self, baudrate):

        # init CS pin
        self.cs.init(self.cs.OUT, value=1)

        # init SPI bus; use low data rate for initialisation
        self.init_spi(100000)

        # clock card at least 100 cycles with cs high
        for i in range(16):
            self.spi.write(b"\xff")

        # CMD0: init card; should return _R1_IDLE_STATE (allow 5 attempts)
        for _ in range(5):
            if self.cmd(0, 0, 0x95) == _R1_IDLE_STATE:
                break
        else:
            raise OSError("no SD card")

        # CMD8: determine card version
        r = self.cmd(8, 0x01AA, 0x87, 4)
        if r == _R1_IDLE_STATE:
            self.init_card_v2()
        elif r == (_R1_IDLE_STATE | _R1_ILLEGAL_COMMAND):
            self.init_card_v1()
        else:
            raise OSError("couldn't determine SD card version")

        # get the number of sectors
        # CMD9: response R2 (R1 byte + 16-byte block read)
        if self.cmd(9, 0, 0, 0, False) != 0:
            raise OSError("no response from SD card")
        csd = bytearray(16)
        self.readinto(csd)
        if csd[0] & 0xC0 == 0x40:  # CSD version 2.0
            self.sectors = ((csd[8] << 8 | csd[9]) + 1) * 1024
        elif csd[0] & 0xC0 == 0x00:  # CSD version 1.0 (old, <=2GB)
            c_size = (csd[6] & 0b11) << 10 | csd[7] << 2 | csd[8] >> 6
            c_size_mult = (csd[9] & 0b11) << 1 | csd[10] >> 7
            read_bl_len = csd[5] & 0b1111
            capacity = (c_size + 1) * (2 ** (c_size_mult + 2)) * (2**read_bl_len)
            self.sectors = capacity // 512
        else:
            raise OSError("SD card CSD format not supported")
        # print('sectors', self.sectors)

        # CMD16: set block length to 512 bytes
        if self.cmd(16, 512, 0) != 0:
            raise OSError("can't set 512 block size")

        # set to high data rate now that it's initialised
        self.init_spi(baudrate)

    def init_card_v1(self):
        for i in range(_CMD_TIMEOUT):
            time.sleep_ms(50)
            self.cmd(55, 0, 0)
            if self.cmd(41, 0, 0) == 0:
                # SDSC card, uses byte addressing in read/write/erase commands
                self.cdv = 512
                # print("[SDCard] v1 card")
                return
        raise OSError("timeout waiting for v1 card")

    def init_card_v2(self):
        for i in range(_CMD_TIMEOUT):
            time.sleep_ms(50)
            self.cmd(58, 0, 0, 4)
            self.cmd(55, 0, 0)
            if self.cmd(41, 0x40000000, 0) == 0:
                self.cmd(58, 0, 0, -4)  # 4-byte response, negative means keep the first byte
                ocr = self.tokenbuf[0]  # get first byte of response, which is OCR
                if not ocr & 0x40:
                    # SDSC card, uses byte addressing in read/write/erase commands
                    self.cdv = 512
                else:
                    # SDHC/SDXC card, uses block addressing in read/write/erase commands
                    self.cdv = 1
                # print("[SDCard] v2 card")
                return
        raise OSError("timeout waiting for v2 card")

    def cmd(self, cmd, arg, crc, final=0, release=True, skip1=False):
        self.cs(0)

        # create and send the command
        buf = self.cmdbuf
        buf[0] = 0x40 | cmd
        buf[1] = arg >> 24
        buf[2] = arg >> 16
        buf[3] = arg >> 8
        buf[4] = arg
        buf[5] = crc
        self.spi.write(buf)

        if skip1:
            self.spi.readinto(self.tokenbuf, 0xFF)

        # wait for the response (response[7] == 0)
        for i in range(_CMD_TIMEOUT):
            self.spi.readinto(self.tokenbuf, 0xFF)
            response = self.tokenbuf[0]
            if not (response & 0x80):
                # this could be a big-endian integer that we are getting here
                # if final<0 then store the first byte to tokenbuf and discard the rest
                if final < 0:
                    self.spi.readinto(self.tokenbuf, 0xFF)
                    final = -1 - final
                for j in range(final):
                    self.spi.write(b"\xff")
                if release:
                    self.cs(1)
                    self.spi.write(b"\xff")
                return response

        # timeout
        self.cs(1)
        self.spi.write(b"\xff")
        return -1

    def readinto(self, buf):
        self.cs(0)

        # read until start byte (0xff)
        for i in range(_CMD_TIMEOUT):
            self.spi.readinto(self.tokenbuf, 0xFF)
            if self.tokenbuf[0] == _TOKEN_DATA:
                break
            time.sleep_ms(1)
        else:
            self.cs(1)
            raise OSError("timeout waiting for response")

        # read data
        mv = self.dummybuf_memoryview
        if len(buf) != len(mv):
            mv = mv[: len(buf)]
        self.spi.write_readinto(mv, buf)

        # read checksum
        self.spi.write(b"\xff")
        self.spi.write(b"\xff")

        self.cs(1)
        self.spi.write(b"\xff")

    def write(self, token, buf):
        self.cs(0)

        # send: start of block, data, checksum
        self.spi.read(1, token)
        self.spi.write(buf)
        self.spi.write(b"\xff")
        self.spi.write(b"\xff")
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

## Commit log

2023-08-04 first commit, CYOCrawler v2.0
    [CYOCRAWLER FEET CONNECTOR X4.stl, CYOCRAWLER FEET X4.stl, CYOCRAWLER FEET CONNECTOR SERVO X4.stl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]
2023-08-19 update crawler default config leg
2023-08-28 patch LED Ring GPIO assignment
2023-08-31 add code support for speaker, play tone, add volume support for tone, add sample wav file
2023-09-04 add code to main to autopopulate the portal config.json everytime it's running, fix portal config template
    [main.py]
2023-09-07 working imu
2023-09-22 fix main so that if the wifi provided cannot connect, roll back to AP MODE and update the config of portal
    [main.py]
2023-09-22 add set custom to matrix, add missing functions to led ring
2023-10-21 add simple startup sequence to know that the board is on
2023-11-12 add ultrasonic support
2023-11-20 replace servo clamp with stronger one
    [CYOCRAWLER HIP SERVO CLAMP X4.stl, CYOCRAWLER HIP SERVO CLAMP v2 X4.stl]
2023-11-26 add factory reset sequence, clean unused libs to prevent stack overflow
    [main.py]
2023-11-26 update light diffuser with ON/OFF imprint, update top cap with better diffuser effect for LED display
    [CYOCRAWLER HEAD LIGHT DIFFUSER X1.stl, CYOCRAWLER HEAD LIGHT DIFFUSER v2 X1.stl, CYOCRAWLER HEAD TOP CAP X1.stl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]
2023-12-01 fix IP scrolling sequence to manual scroll using buttons
    [main.py]
2023-12-01 fix speaker alloc mem problem (again), add new sequence for AP MODE and IP scrolling (manual), fix thread lock problem associated with these new sequences
    [main.py]
2023-12-02 update pomodoro timer challenge
2023-12-09 add led chasing game challenge
2023-12-16 add ultrasonic radar challenge
2023-12-19 fix CORS, add del file and outfile because config file is getting bigger and bigger, will have mem alloc error
    [main.py]
2023-12-23 add IMU counter challenge
2023-12-30 fix bug in main.py /api/wifi to reset even when connection is unsuccessful. Fix wireless.py to run short interval of 5 seconds, and main.py to call connect 4 times
    [main.py]
2023-12-30 new portal support block programming, manual robot IP address and webrepl IP change, activity loading and playing, improved flow
2024-01-03 clean kinematics.py file
2024-02-03 add simple imu gimbal challenge
